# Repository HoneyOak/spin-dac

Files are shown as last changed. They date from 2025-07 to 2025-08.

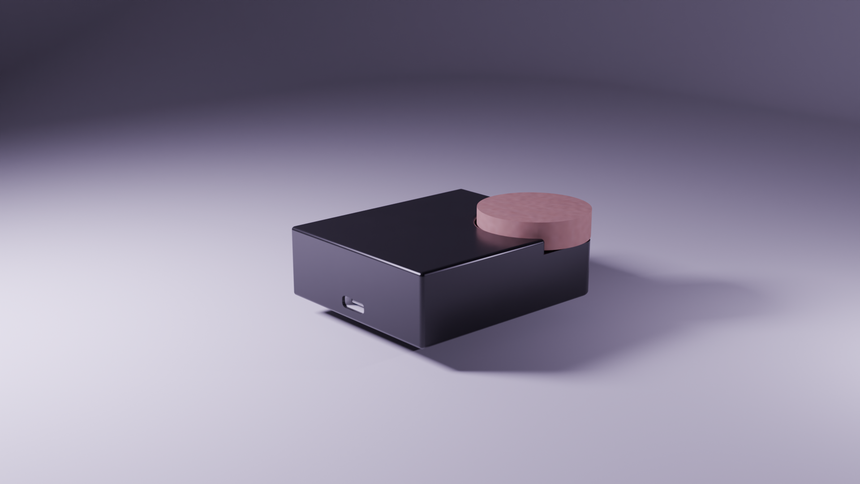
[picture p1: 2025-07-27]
images/render-1.png

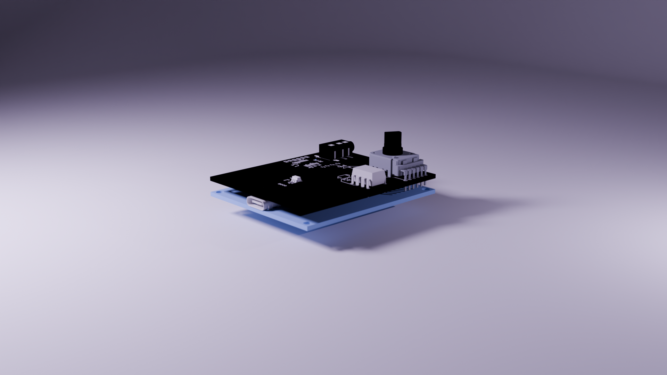
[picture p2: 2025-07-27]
images/render-2.png

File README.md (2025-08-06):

# Spin DAC
A Digital-Analog Converter (DAC) is used for... well, exactly that. Particularly, I want to make a high-quality DAC that converts digital music signals into analog signals for headphones/speakers. Commercial options are quite expensive and big. It is, however, (theoretically) possible to build a budget portable DAC.

This project features a compact, yet high-quality, USB-C DAC, with an inbuilt op-amp. With this, we can acheive significantly better sound quality, with extremely low noise, on any usb-c device.

# Features
- upto 24 bit 192kHz audio
- Ultra Low Noise
- USB-C input
- Seperated Analog and Digital Signals on PCB
- 4 layer PCB to avoid noise and EMI
- 3.5 mm output jack

# Images
render-1

render-2

## PCB




## CAD


## Schematic


# BOM

**Total price: $94.38**

| name | quantity | price | total | notes | link |
| --- | --- | --- | ----- | --- | --- |
| USB to I2S Module cm6631a | 1 | 40.82 | 40.82 | cheapest available amazon, | [https://www.amazon.com/Generic-CM6631A-Digital-Interface-Converter/dp/B0D47Q1MNB/ref=sr_1_1](https://www.amazon.com/Generic-CM6631A-Digital-Interface-Converter/dp/B0D47Q1MNB/ref=sr_1_1) |
| USB C Connector | 1 | 0.1849710983 | 0.18  | | [https://electrostoreshop.com/product/type-c-usb-female-to-dip-pcb-breakout-board/](https://electrostoreshop.com/product/type-c-usb-female-to-dip-pcb-breakout-board/) |
| PCM5102A | 1 | 18.26589595 | 18.27 | only available on digikey, so included shipping here | [https://www.digikey.in/en/products/detail/texas-instruments/PCM5102APWR/4341334](https://www.digikey.in/en/products/detail/texas-instruments/PCM5102APWR/4341334) |
| LDO - LP5907 | 1 | 0.3005780347 | 0.30  | | [https://www.electronicscomp.com/lp5907mfx-33-nopb-texas-instruments-fixed-ldo-voltage-regulator-22v-to-55v-250mv-dropout-33vout-250maout-sot-23-5](https://www.electronicscomp.com/lp5907mfx-33-nopb-texas-instruments-fixed-ldo-voltage-regulator-22v-to-55v-250mv-dropout-33vout-250maout-sot-23-5) |
| Dual Gang Potentiometer | 1 | 1.398843931 | 1.40  | | [https://in.rsdelivers.com/product/bourns/ptv112-4420a-b503/bourns-ptv-50k%CF%89-rotary-potentiometer-2-gang-hole/6930702](https://in.rsdelivers.com/product/bourns/ptv112-4420a-b503/bourns-ptv-50k%CF%89-rotary-potentiometer-2-gang-hole/6930702) |
| OPA2134PA | 1 | 6.523255814 | 6.52  | | [https://www.digikey.in/en/products/detail/texas-instruments/OPA2134PA/254686](https://www.digikey.in/en/products/detail/texas-instruments/OPA2134PA/254686) |
| 3.5mm Audio Jack | 1 | 0.2403468208 | 0.24  | | [https://sharvielectronics.com/product/audio-jack-3-5mm-trrs-smd/](https://sharvielectronics.com/product/audio-jack-3-5mm-trrs-smd/) |
| | | | | | |
| capacitors | | | | | |
| 1uf | 2 | 0.01156069364  | 0.02  | C1,C2 | [https://www.ktron.in/product/1uf-50v-ceramic-capacitor-mlcc-smd-0603/?v=c86ee0d9d7ed](https://www.ktron.in/product/1uf-50v-ceramic-capacitor-mlcc-smd-0603/?v=c86ee0d9d7ed) |
| 39nf | 2 | 0.2080924855 | 0.42  | C3,C12 | [https://www.electronicscomp.com/39nf-50v-smd-capacitor-0603-package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](https://www.electronicscomp.com/39nf-50v-smd-capacitor-0603-package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) |
| 0.1uf | 4 | 0.01156069364  | 0.05  | C4,C7,C8,C15 | [https://www.ktron.in/product/100nf-16v-ceramic-capacitor-smd-0603/?v=c86ee0d9d7ed](https://www.ktron.in/product/100nf-16v-ceramic-capacitor-smd-0603/?v=c86ee0d9d7ed) |
| 2.2uf | 2 | 0.02138728324  | 0.04  | C5,C6 | [https://www.ktron.in/product/2-2uf-10v-multi-layer-ceramic-capacitor/?v=c86ee0d9d7ed](https://www.ktron.in/product/2-2uf-10v-multi-layer-ceramic-capacitor/?v=c86ee0d9d7ed) |
| 10uf | 1 | 0.02138728324  | 0.02  | C9 | [https://www.ktron.in/product/10uf-25v-multi-layered-ceramic-capacitor-2/?v=c86ee0d9d7ed](https://www.ktron.in/product/10uf-25v-multi-layered-ceramic-capacitor-2/?v=c86ee0d9d7ed) |
| 2.2nf | 2 | 0.008092485549 | 0.02  | C10,C11 | [https://www.ktron.in/product/2-nf-50v-mlcc-x7r-smd-0603-yageo/?v=c86ee0d9d7ed](https://www.ktron.in/product/2-nf-50v-mlcc-x7r-smd-0603-yageo/?v=c86ee0d9d7ed) |
| 1nf | 2 | 0.005549132948 | 0.01  | C13,C14 | [https://www.ktron.in/product/1nf-50v-multi-layered-ceramic-capacitor-mlcc-smd-0603/?v=c86ee0d9d7ed](https://www.ktron.in/product/1nf-50v-multi-layered-ceramic-capacitor-mlcc-smd-0603/?v=c86ee0d9d7ed) |
| | | | | | |
| resistors | | | | | |
| 590 Ohm | 2 | 0.01156069364  | 0.02  | R1,R4 | [https://www.evelta.com/590-ohm-1-0603-thick-film-chip-resistor-0603waf5900t5e/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](https://www.evelta.com/590-ohm-1-0603-thick-film-chip-resistor-0603waf5900t5e/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) |
| 470 Ohm | 2 | 0.002543352601 | 0.01  | R2,R3 | [https://www.ktron.in/product/resistor-470e-1-10w-1-smd-0603/?v=c86ee0d9d7ed](https://www.ktron.in/product/resistor-470e-1-10w-1-smd-0603/?v=c86ee0d9d7ed) |
| 499 Ohm | 2 | 0.01156069364  | 0.02  | R5,R6 | [https://www.evelta.com/499-ohm-1-0603-thick-film-chip-resistor-0603waf4990t5e/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](https://www.evelta.com/499-ohm-1-0603-thick-film-chip-resistor-0603waf4990t5e/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) |
| 2.49 kOhm | 2 | 0.002543352601 | 0.01  | R7,R8 | [https://www.ktron.in/product/resistor-2-49k-ohms-1-1-10w-smd-0603-copy/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](https://www.ktron.in/product/resistor-2-49k-ohms-1-1-10w-smd-0603-copy/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) |
| PCB Fabrication | 1 | 26.01156069 | 26.01 | | [https://www.lioncircuits.com](https://www.lioncircuits.com) |
| TOTAL | | | 94.38 | | |

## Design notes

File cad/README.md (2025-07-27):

Onshape link:
https://cad.onshape.com/documents/52299f4d1c8722daa58ef851/w/3add91a0811deec572a7f1c0/e/bb5ea1597d2023aa287f9285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

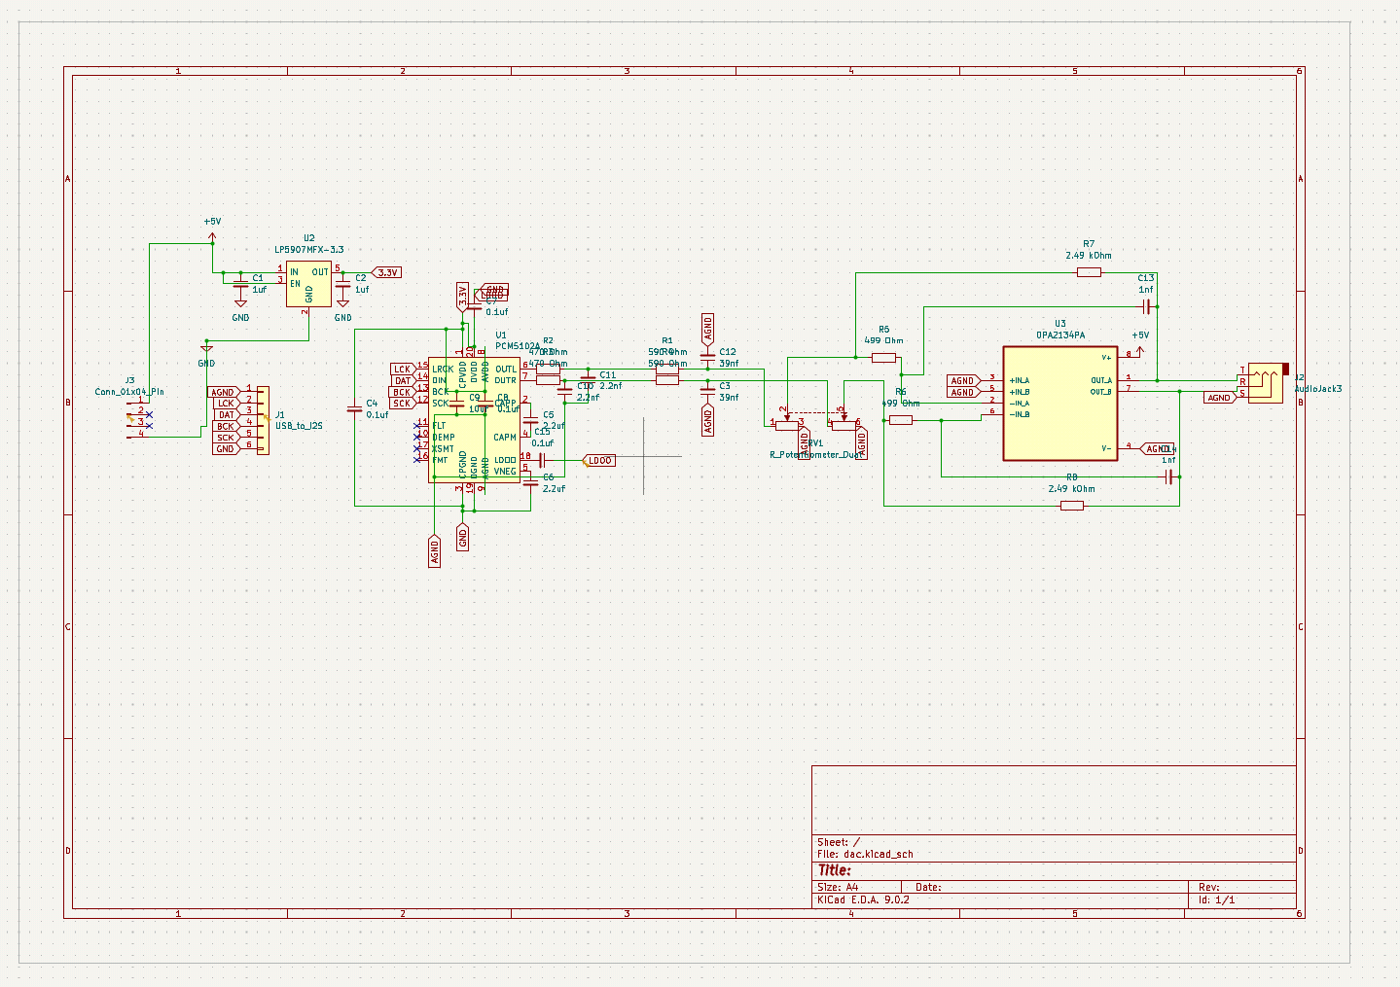
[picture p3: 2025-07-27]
images/schematic.png

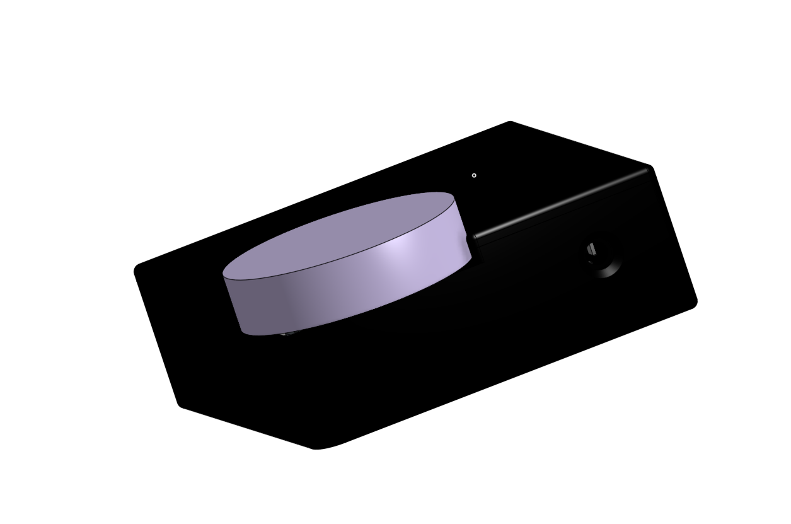
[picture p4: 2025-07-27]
images/onshape.png

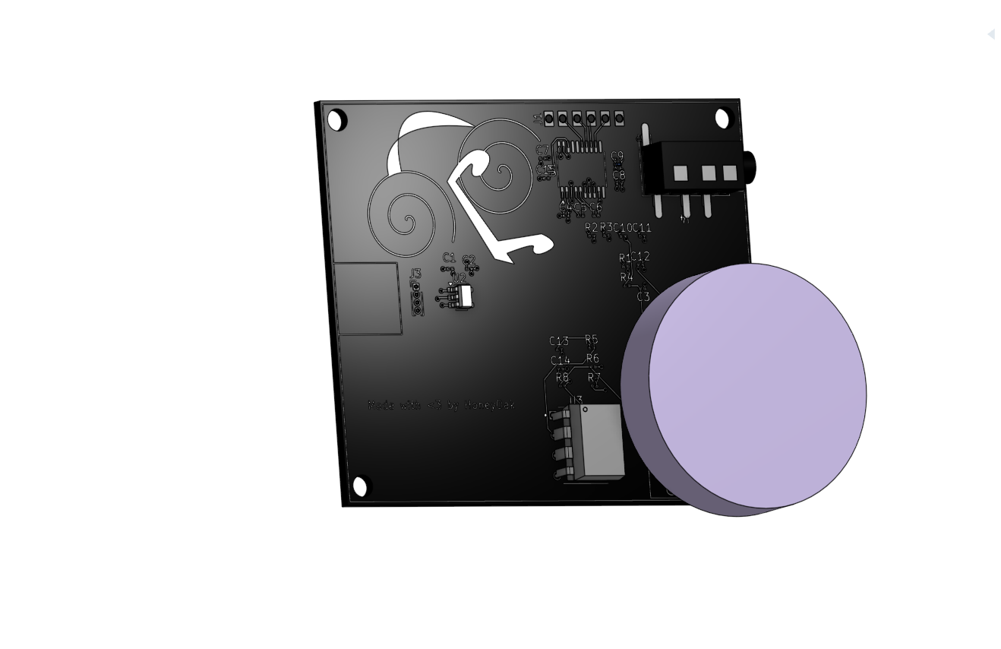
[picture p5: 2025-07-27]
images/pcb-render.png

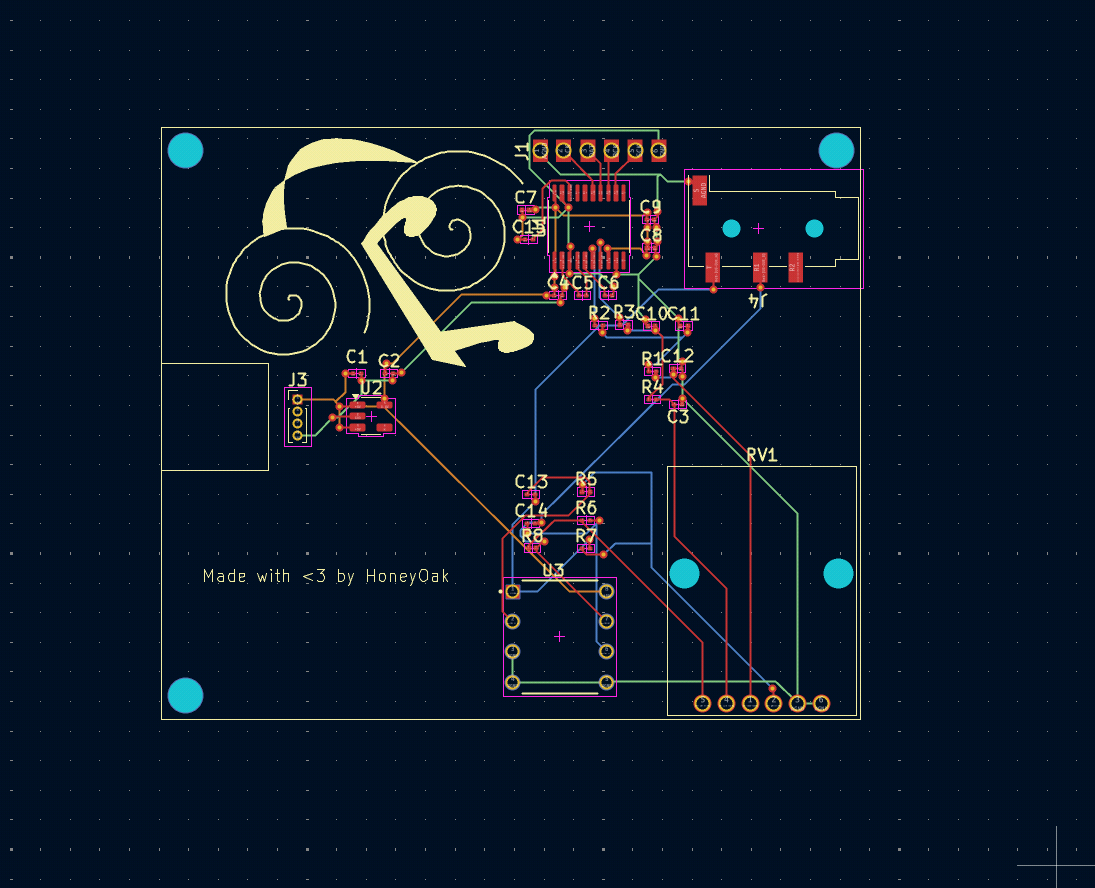
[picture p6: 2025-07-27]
images/pcb.png

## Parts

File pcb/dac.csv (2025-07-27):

Reference | Qty | Value | DNP | Exclude from BOM | Exclude from Board | Footprint | Datasheet
C1,C2 | 2 | 1uf |  |  |  | Capacitor_SMD:C_0201_0603Metric | ~
C3,C12 | 2 | 39nf |  |  |  | Capacitor_SMD:C_0201_0603Metric | ~
C4,C7,C8,C15 | 4 | 0.1uf |  |  |  | Capacitor_SMD:C_0201_0603Metric | ~
C5,C6 | 2 | 2.2uf |  |  |  | Capacitor_SMD:C_0201_0603Metric | ~
C9 | 1 | 10uf |  |  |  | Capacitor_SMD:C_0201_0603Metric | ~
C10,C11 | 2 | 2.2nf |  |  |  | Capacitor_SMD:C_0201_0603Metric | ~
C13,C14 | 2 | 1nf |  |  |  | Capacitor_SMD:C_0201_0603Metric | ~
J1 | 1 | USB_to_I2S |  |  |  | dac:USB_I2S_Module | ~
J3 | 1 | Conn_01x04_Pin |  |  |  | Connector_PinHeader_1.00mm:PinHeader_1x04_P1.00mm_Vertical | ~
J4 | 1 | AudioJack4 |  |  |  | Connector_Audio:Jack_3.5mm_KoreanHropartsElec_PJ-320D-4A_Horizontal | ~
R1,R4 | 2 | 590 Ohm |  |  |  | Resistor_SMD:R_0201_0603Metric | ~
R2,R3 | 2 | 470 Ohm |  |  |  | Resistor_SMD:R_0201_0603Metric | ~
R5,R6 | 2 | 499 Ohm |  |  |  | Resistor_SMD:R_0201_0603Metric | ~
R7,R8 | 2 | 2.49 kOhm |  |  |  | Resistor_SMD:R_0201_0603Metric | ~
RV1 | 1 | R_Potentiometer_Dual |  |  |  | dac:Dual_Gang_POT | ~
U1 | 1 | PCM5102A |  |  |  | Package_SO:TSSOP-20_4.4x6.5mm_P0.65mm | https://www.ti.com/lit/ds/symlink/pcm5102a.pdf
U2 | 1 | LP5907MFX-3.3 |  |  |  | Package_TO_SOT_SMD:SOT-23-5 | http://www.ti.com/lit/ds/symlink/lp5907.pdf
U3 | 1 | OPA2134PA |  |  |  | OPA2134PA:DIP794W45P254L959H508Q8

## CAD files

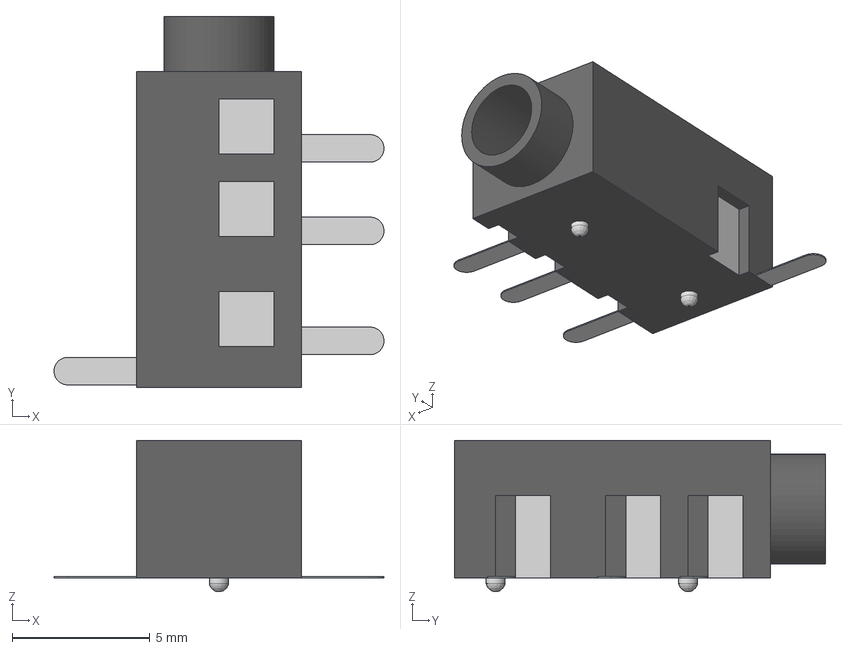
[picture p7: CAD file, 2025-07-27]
pcb/audio_3.5mm_trrs.step
12.0 x 13.5 x 5.50 mm

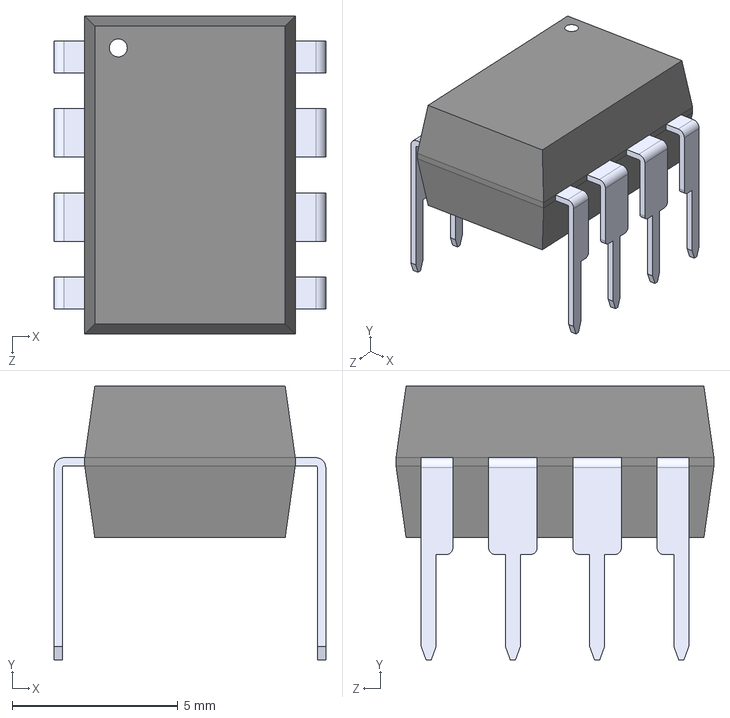
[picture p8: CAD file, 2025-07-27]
pcb/OPA2134PA/OPA2134PA.step
8.19 x 8.26 x 9.59 mm

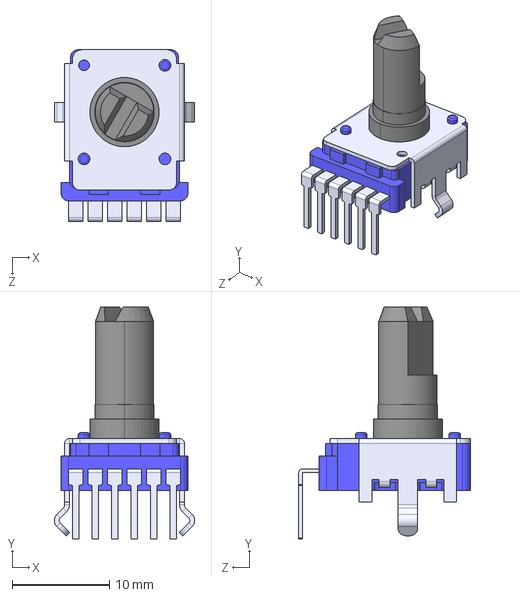
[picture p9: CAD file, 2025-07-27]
pcb/PTV112-4420A-B503--3DModel-STEP-269445/PTV112-4420A-B503--3DModel-STEP-269445.STEP
14.4 x 23.8 x 17.6 mm

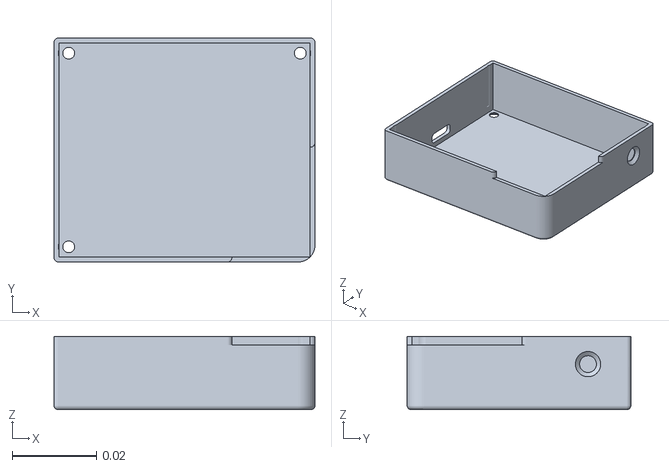
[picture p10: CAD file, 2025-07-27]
production/housing - bottom_case.stl
0.062 x 0.0532 x 0.0174

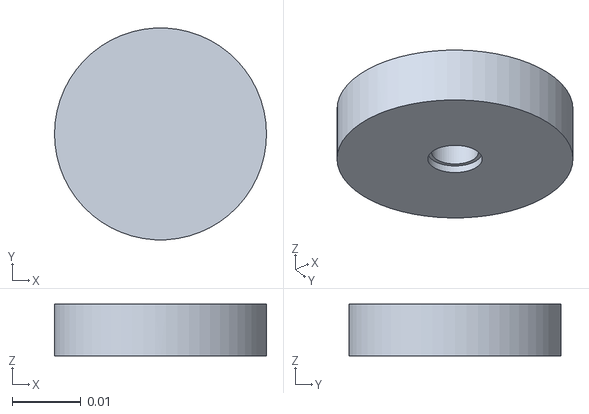
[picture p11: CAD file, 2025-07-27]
production/knob.stl
0.0308 x 0.0308 x 0.00752

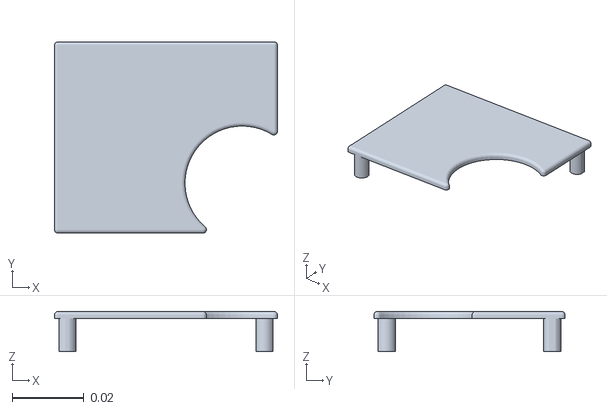
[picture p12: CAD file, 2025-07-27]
production/housing - upper.stl
0.062 x 0.0532 x 0.0112

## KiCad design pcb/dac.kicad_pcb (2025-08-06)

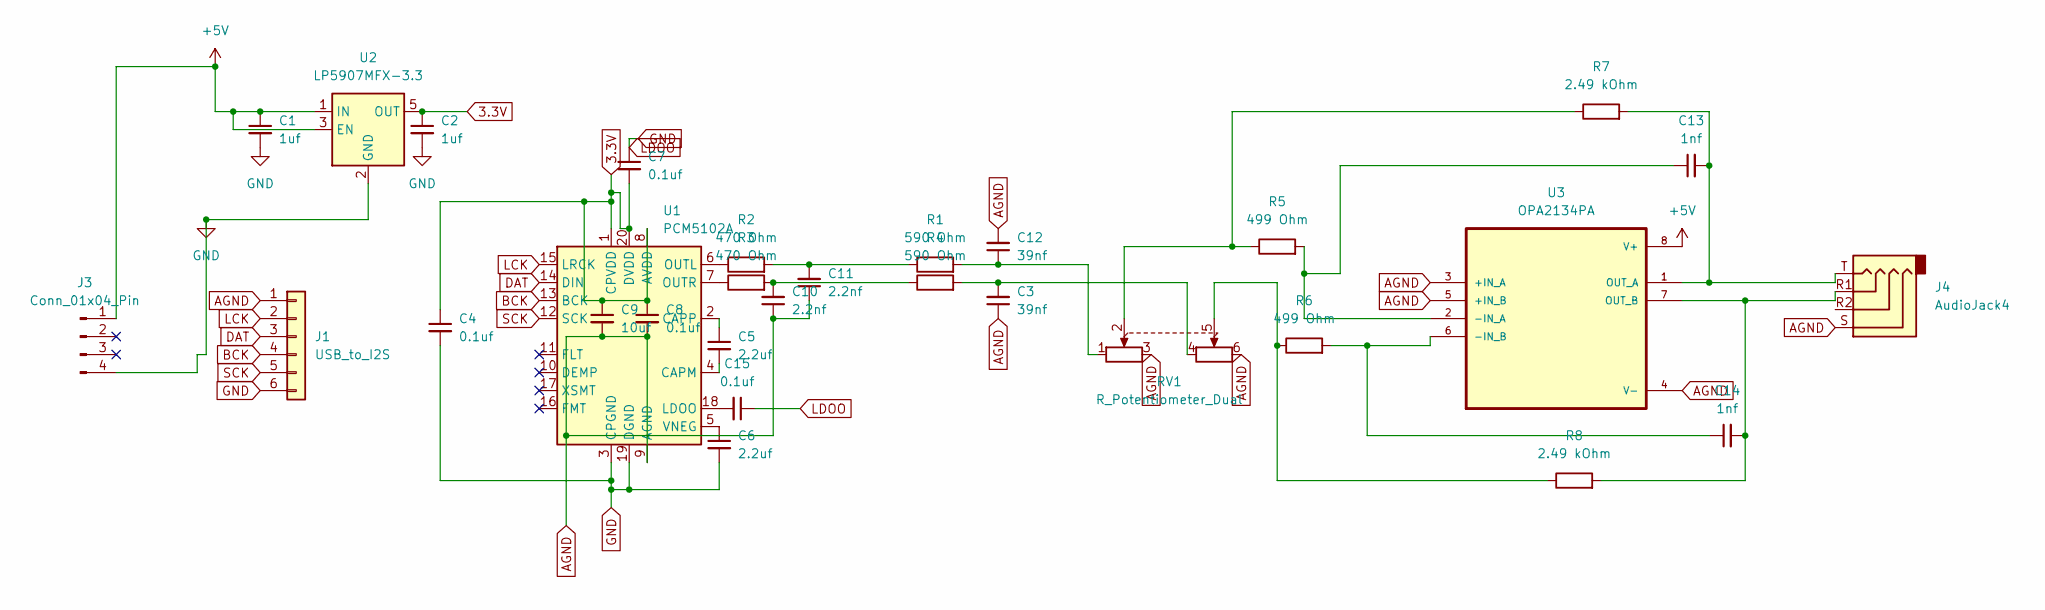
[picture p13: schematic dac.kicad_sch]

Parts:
C1, C2: 1uf; C_0201_0603Metric
C3, C12: 39nf; C_0201_0603Metric
C4, C7, C8, C15: 0.1uf; C_0201_0603Metric
C5, C6: 2.2uf; C_0201_0603Metric
C9: 10uf; C_0201_0603Metric
C10, C11: 2.2nf; C_0201_0603Metric
C13, C14: 1nf; C_0201_0603Metric
J1: USB_to_I2S; USB_I2S_Module
J3: Conn_01x04_Pin; PinHeader_1x04_P1.00mm_Vertical
J4: AudioJack4; Jack_3.5mm_KoreanHropartsElec_PJ-320D-4A_Horizontal
R1, R4: 590 Ohm; R_0201_0603Metric
R2, R3: 470 Ohm; R_0201_0603Metric
R5, R6: 499 Ohm; R_0201_0603Metric
R7, R8: 2.49 kOhm; R_0201_0603Metric
RV1: R_Potentiometer_Dual; Dual_Gang_POT
U1: PCM5102A; TSSOP-20_4.4x6.5mm_P0.65mm
U2: LP5907MFX-3.3; SOT-23-5
U3: OPA2134PA; DIP794W45P254L959H508Q8

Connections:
3.3V: C2.1, C4.1, C7.2, C8.1, C9.1, U1.1 (CPVDD), U1.8 (AVDD), U1.20 (DVDD), U2.5 (OUT)
+5V: C1.1, J3.1, U2.1 (IN), U2.3 (EN), U3.8 (V+)
AGND: C3.1, C8.2, C9.2, C10.1, C11.1, C12.2, J1.1, J4.S, RV1.3, RV1.6, U1.9 (AGND), U3.3 (+IN_A), U3.4 (V-), U3.5 (+IN_B)
BCK: J1.4, U1.13 (BCK)
DAT: J1.3, U1.14 (DIN)
GND: C1.2, C2.2, C4.2, C6.2, C7.1, C15.1, J1.6, J3.4, U1.3 (CPGND), U1.19 (DGND), U2.2 (GND)
LCK: J1.2, U1.15 (LRCK)
unnamed: C3.2, R4.2, RV1.4
unnamed: C10.2, R3.2, R4.1
unnamed: C11.2, R1.1, R2.2
unnamed: C12.1, R1.2, RV1.1
unnamed: R5.1, R7.1, RV1.2
unnamed: R6.1, R8.1, RV1.5
unnamed: C5.2, U1.4 (CAPM)
unnamed: C5.1, U1.2 (CAPP)
unnamed: C15.2, U1.18 (LDOO)
unnamed: R2.1, U1.6 (OUTL)
unnamed: R3.1, U1.7 (OUTR)
unnamed: C6.1, U1.5 (VNEG)
unnamed: C13.1, R5.2, U3.2 (-IN_A)
unnamed: C14.1, R6.2, U3.6 (-IN_B)
unnamed: C13.2, J4.T, R7.2, U3.1 (OUT_A)
unnamed: C14.2, J4.R1, R8.2, U3.7 (OUT_B)
SCK: J1.5, U1.12 (SCK)

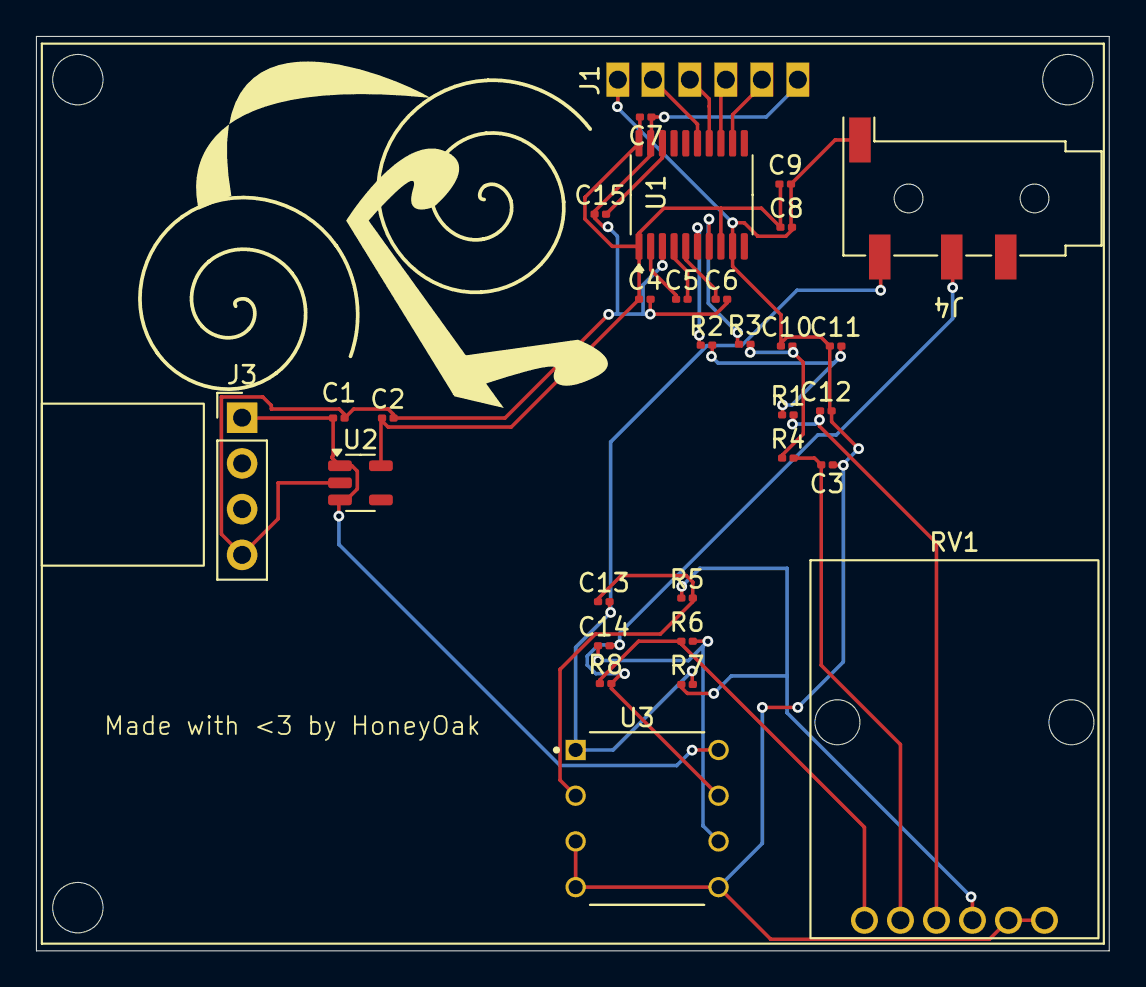
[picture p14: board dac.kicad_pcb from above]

Board: 2 copper layers, 59.6 x 50.8 mm, 30 parts (0 on the bottom side), 24 nets.

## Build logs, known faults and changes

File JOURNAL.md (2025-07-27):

---
title: Spin Amp
author: HoneyOak
description: USB-C DAC
created_at: 2025-07-25
---

~ [hack club highway](highway.hackclub.com)

#### Total time spent so far: ~16 hours

## 2025-07-24 Research (3 hours)
I found out that existing commmercial solutions are expensive, and there aren't many existing projects that implement a compact, budget DAC. There are plenty guides, though. I found a few from which I can get an idea of the BOM and feasability, as well as the rough circuit diagram.
This shouldn't be extremely difficult to pull off. Sure, I would have to maintain a clean circuit and prevent noise. But the circuit itself has 3 major components: USB to I2S, DAC, and OP-amp (and I'm adding a potentiometer for analog volume control).
Existing projects gave me lots of confidence though (some even handwired!): https://orronoco.blogspot.com/2022/01/build-your-own-portable-usb-dac.html, https://summivox.wordpress.com/2016/12/14/making-myself-a-usb-dac-headphone-amp-part-1/
That said, I have never made a 4-layer PCB before (or really, never made a pcb at all yet). So this would be a fun challenge! 

## 2025-07-25 Schematic (6.5 hours)
Done with the schematic today! Phew. That took a lot of research. Selecting the right modules, getting the right footprints, and scrolling through datasheet after datasheet to find the correct configuration. Finally, though, I think I'm done with possibly the hardest part of this build!



## 2025-07-26 PCB (2 hours)
Arranged the PCB Layout, placing caps and resistors in optimal positions. Using a 4 layer PCB would greatly reduce noise and electromagnetic interference, which is particulary important for a high quality audio device.



## 2025-07-26 More KiCAD (4.5 hours)
Done with PCB!!! took a while to have everything routed because I had to be very careful with what layer each trace needs to go to.



## 2025-07-27 CAD and renders (5.5 hours)
Whipped up a case in OnShape real quick. Added screw holes + knob.



Also did some renders in blender!

render-2
render-1

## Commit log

2025-08-05 Update pcb
    [OPA2134PA.step, PTV112-4420A-B503--3DModel-STEP-269445.STEP, audio_3.5mm_trrs.step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]
2025-08-05 update gerbers
